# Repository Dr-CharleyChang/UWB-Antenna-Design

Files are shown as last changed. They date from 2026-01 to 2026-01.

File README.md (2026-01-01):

# Fire-Gecko UWB Antenna (火壁虎-超宽带穿墙雷达天线)


[]()
[]()

[English Version](#english-introduction) | [中文介绍](#chinese-introduction)

---

## 🦎 English Introduction

### 🎯 Project Context

This project is the RF front-end subsystem for the **Fire-Gecko Through-Wall Radar**.
It is designed for post-disaster rescue and aims to detect vital signs (heartbeat/respiration) of stationary targets behind walls using SFCW radar technology.

### 🧬 Design Highlights

* **Architecture**: Teardrop Dipole with Resistive Loading.
* **Core Frequency**: 1.2 GHz (optimized for wall penetration).
* **Innovation**: Uses a **12Ω resistor** to dampen the high-Q resonance, achieving a flat UWB response (0.9-1.8 GHz) suitable for SFCW transmission.
* **Performance**: **S11 < -15 dB** @ 1.2 GHz, **Gain 3.62 dBi**.

### 📂 Repository Structure

* `models/`: HFSS simulation files (`.aedt`) and DXF fabrication files.
* `docs/`: **[Engineering Log](docs/Engineering_Log.md)** (Detailed design history & failure analysis).
* `hardware/`: Gerber files for PCB manufacturing.

*(See detailed design process and simulation plots in the Engineering Log)*

---

## 🦎 中文介绍 (Chinese Introduction)

### 🎯 项目背景

本项目是 **Fire-Gecko (火壁虎) 穿墙生命探测雷达** 的天线子系统。
针对废墟搜救场景，我们需要一只“穿墙的眼睛”。本设计旨在提供一个高穿透力 (1.2 GHz) 且具有高距离分辨率 (UWB) 的定向天线方案。

### 🧬 技术亮点

* **架构**: 电阻加载式水滴形偶极子 (Resistively Loaded Teardrop Dipole)。
* **核心指标**: 中心频率 **1.2 GHz**，带宽覆盖 **0.9 - 1.8 GHz**。
* **设计突破**: 针对早期版本“高Q值窄带谐振”的问题，创新性地引入 **12Ω 并联电阻**，成功将尖锐的谐振峰压平，实现了良好的超宽带匹配。
* **最终性能**: 反射系数 S11 低至 **-15 dB**，增益 **3.62 dBi**，具有优异的单向辐射特性。

### 📂 目录说明

* `models/`: HFSS 仿真源文件及 DXF 结构图。
* `docs/`: **[工程设计日志](docs/Engineering_Log.md)** (包含从 V1 失败到 V3 成功的完整复盘记录与波形图)。
* `hardware/`: PCB 打样制造文件 (Gerber)。

---

**Maintainer**: Chief Architect, Fire-Gecko Team

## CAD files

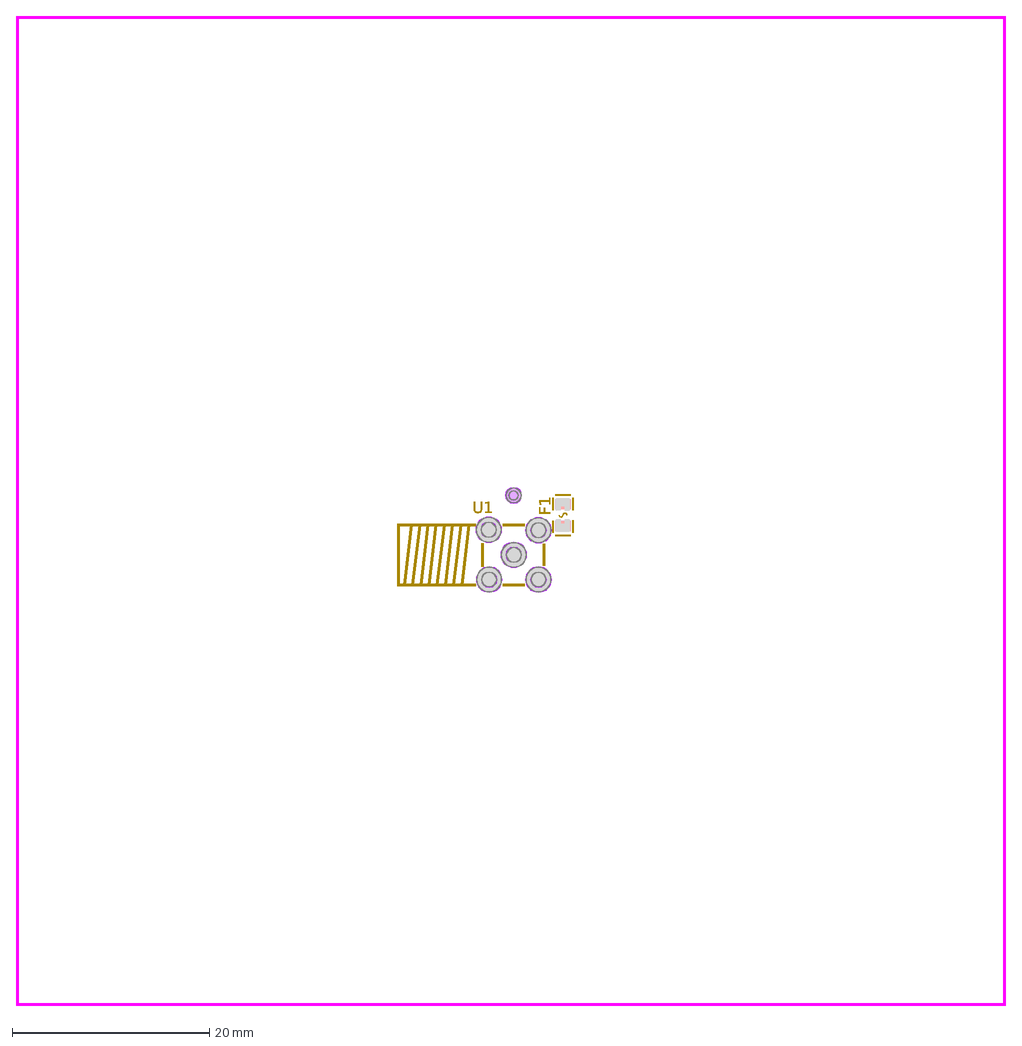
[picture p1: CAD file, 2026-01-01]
models/Antenna_Outline.dxf
F1
U1

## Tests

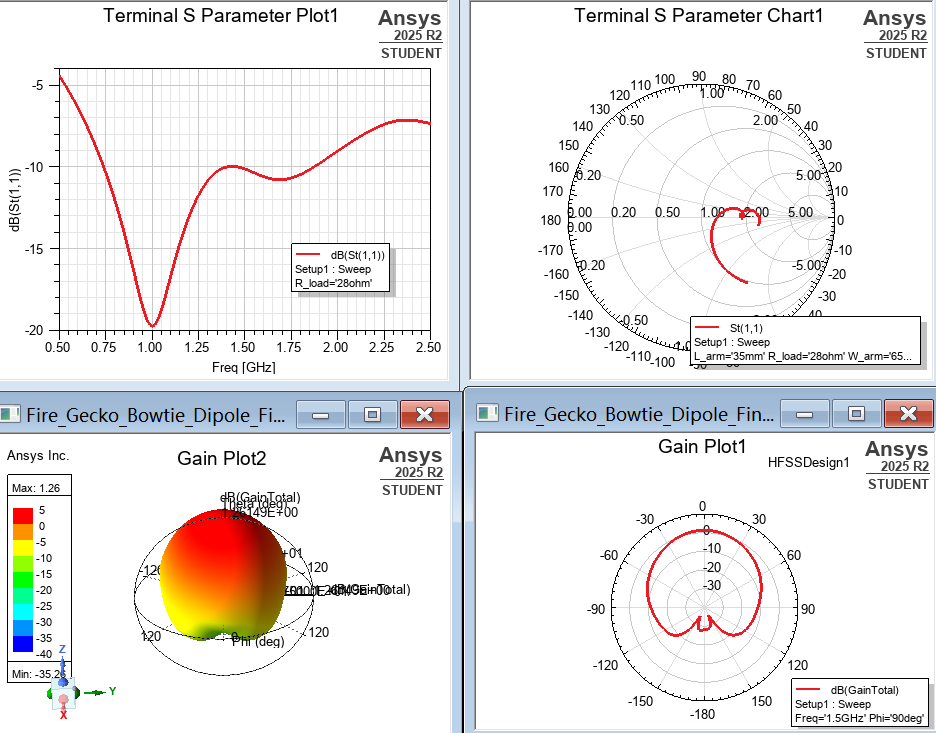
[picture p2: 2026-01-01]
images/V3.0_HFSS_Results.PNG

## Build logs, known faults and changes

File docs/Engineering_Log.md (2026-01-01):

# Fire-Gecko UWB Antenna Engineering Log

# 火壁虎雷达天线工程设计日志

**Project**: Fire-Gecko Through-Wall Radar
**Component**: RF Front-end / UWB Antenna
**Date**: 2026-01-01
**Version**: v1.0 (Final Release)
**Status**: Frozen for Fabrication / 定型投产

---

## 1. 设计目标 (Design Objectives)

**[CN]**
针对 SFCW (步进频率连续波) 穿墙雷达系统，设计一款满足以下指标的天线：

* **中心频率**: 1.2 GHz (兼顾穿墙能力与分辨率)
* **带宽**: 0.8 GHz - 1.8 GHz (超宽带 UWB)
* **S11**: < -10 dB (全频段)，中心频点 < -15 dB
* **结构**: 平面印制板 (PCB) + 金属背腔 (Cavity)

**[EN]**
Design an antenna for the SFCW Through-Wall Radar system meeting the following specs:

* **Center Freq**: 1.2 GHz (Balance between penetration and resolution).
* **Bandwidth**: 0.8 GHz - 1.8 GHz (UWB).
* **S11**: < -10 dB (full band), < -15 dB @ Center Freq.
* **Structure**: PCB + Metal Back Cavity.

---

## 2. 设计演进与复盘 (Design Evolution & Analysis)

### Phase 1: 梯形偶极子 (Trapezoidal Dipole) - [FAILED]

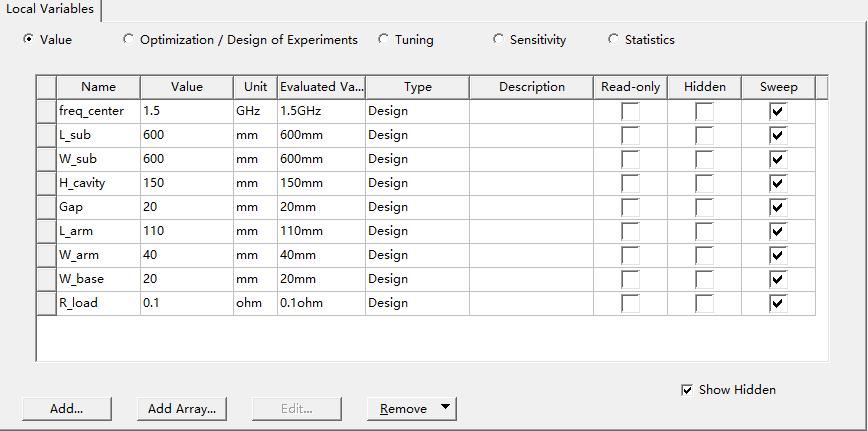
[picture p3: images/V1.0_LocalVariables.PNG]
Variables for V1


**[CN] 现象与分析：**

* **现象**: S11 曲线几乎贴着 0 dB 线震荡，表现为全反射，无法匹配。
* **死因 1 (尖角效应)**: 梯形结构在馈电处存在尖锐折角。高频电流在尖角处无法顺滑流动，产生强烈的寄生电容和反射。*这就像水流在直角弯管处被堵回来了一样。*
* **死因 2 (背腔窒息)**: 初始背腔深度 ($H=150\text{ mm}$) 过深，远大于 1/4 波长。反射波与发射波相位相反 (180°)，两者相互抵消，导致辐射电阻趋近于零，能量被“闷”死在天线里。

**[EN] Observation & Analysis:**

* **Observation**: The S11 curve oscillates near 0 dB, indicating total reflection and mismatch.
* **Root Cause 1 (Corner Effect)**: Sharp corners at the feed point caused severe impedance discontinuity. High-frequency currents could not flow smoothly, creating parasitic capacitance. *Analogy: Water flow blocked by a sharp right-angle pipe.*
* **Root Cause 2 (Cavity Choking)**: The initial cavity depth ($H=150\text{ mm}$) was too deep (>> $\lambda/4$). The reflected wave was 180° out of phase with the incident wave, causing destructive interference. The radiation resistance dropped to near zero, effectively choking the radiation.

**📸 仿真截图 (Simulation Plots):**

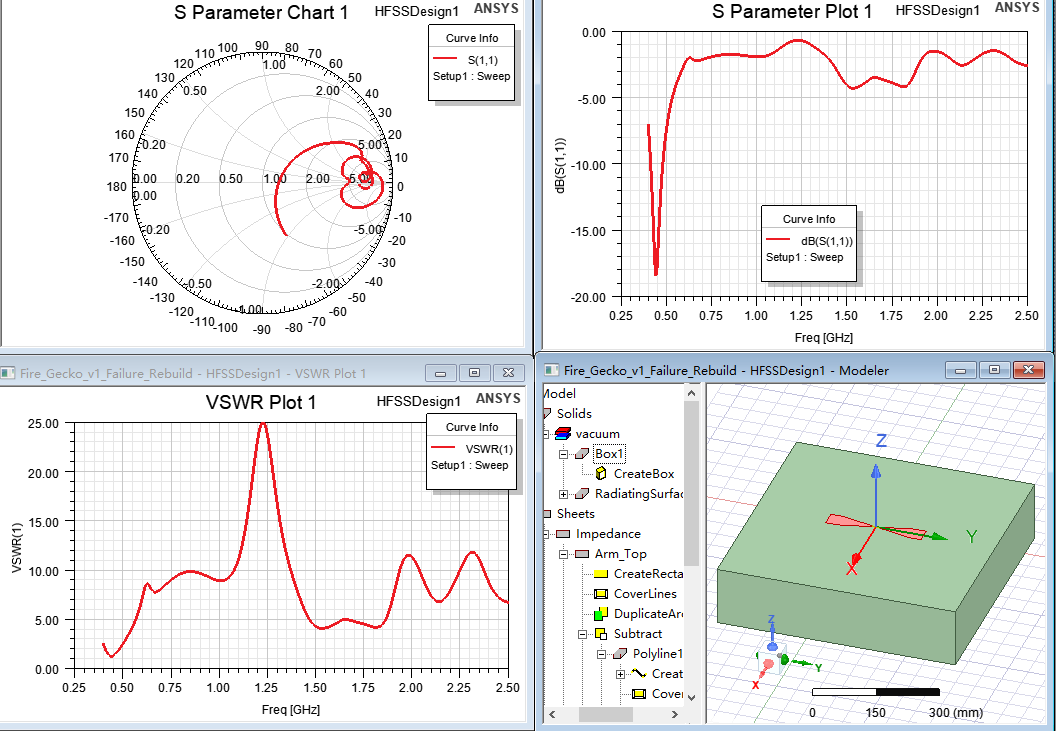
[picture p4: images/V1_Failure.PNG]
V1 S11 Failure


---

### Phase 2: 水滴形渐变 (Teardrop Taper) - [POOR PERFORMANCE]

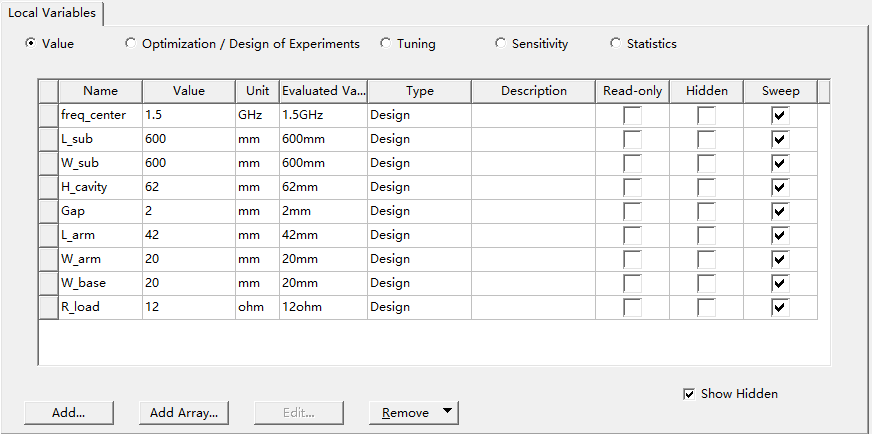
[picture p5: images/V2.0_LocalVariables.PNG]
Variables for V2


**[CN] 现象与分析：**

* **改进**: 引入指数渐变 (Teardrop) 消除尖角。
* **现象**: S11 出现改善，但在 1 GHz 处出现一个极窄的深坑 (-38 dB)，其他频段依然很差。
* **死因 (高 Q 值谐振)**: 此时天线变成了一个 **高 Q 值谐振器**（像一个铃铛）。它只在特定频率“响”得很大声，但带宽极窄。雷达发射宽带信号时，这种天线会引入严重的信号失真（振铃效应），无法使用。

**[EN] Observation & Analysis:**

* **Improvement**: Introduced exponential teardrop taper to eliminate sharp corners.
* **Observation**: S11 improved but showed a very narrow, deep dip (-38 dB) at 1 GHz, acting like a high-Q resonator.
* **Root Cause (High-Q Resonance)**: The antenna acted like a "bell" — resonating strongly at a single frequency but lacking bandwidth. For UWB radar, this high-Q characteristic causes severe signal distortion (ringing) and is unusable.

**📸 仿真截图 (Simulation Plots):**

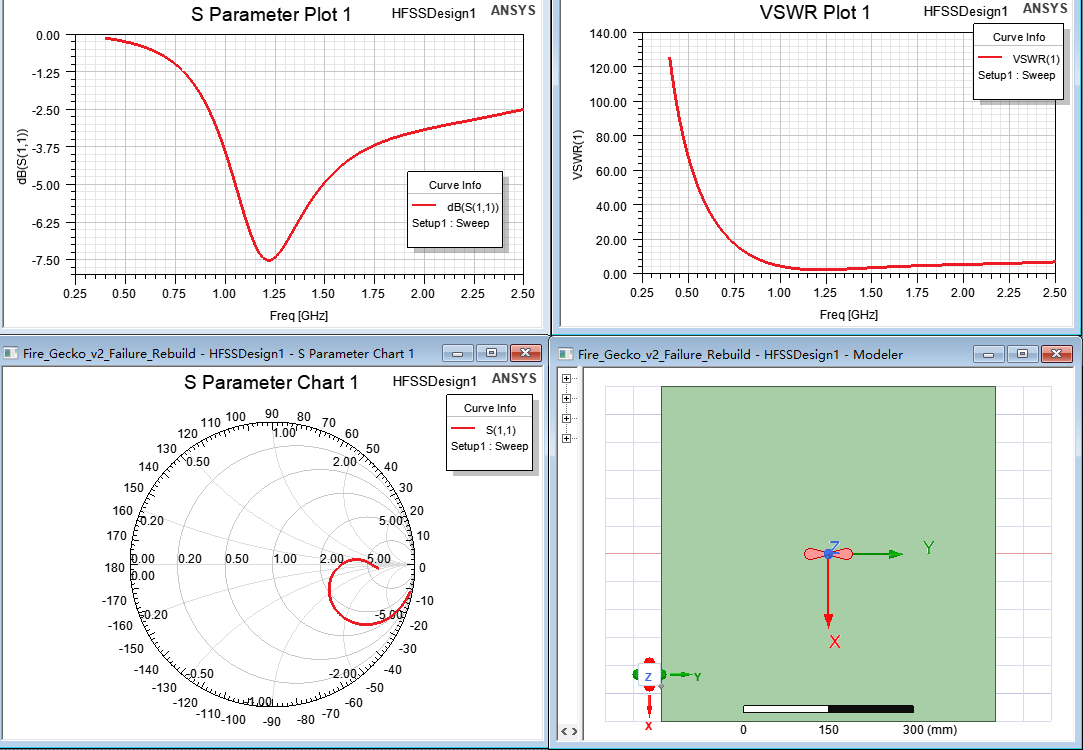
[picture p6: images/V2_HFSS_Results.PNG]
V2 Narrow Band Resonance


---

### Phase 3: 最终定型 (Final Release V3) - [SUCCESS]

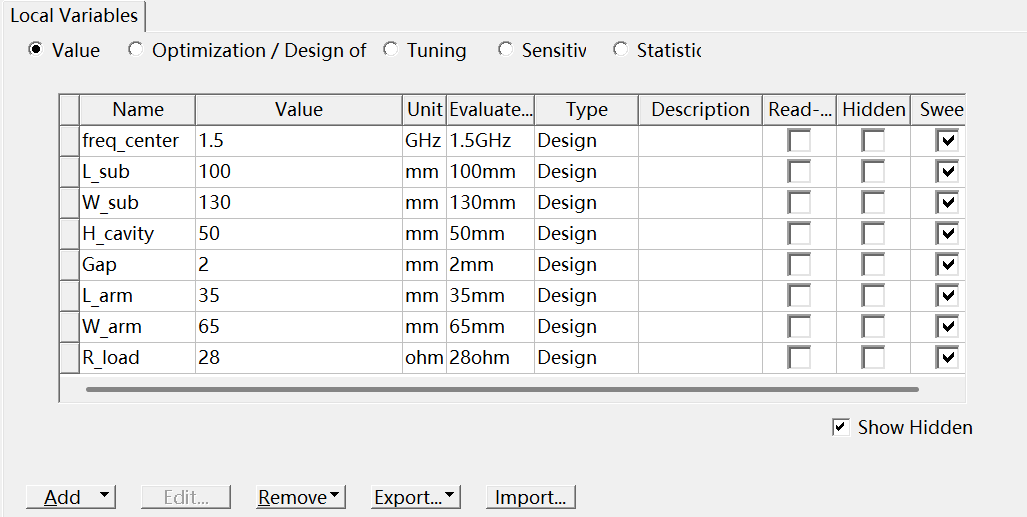
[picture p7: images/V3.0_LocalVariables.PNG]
Variables for V3


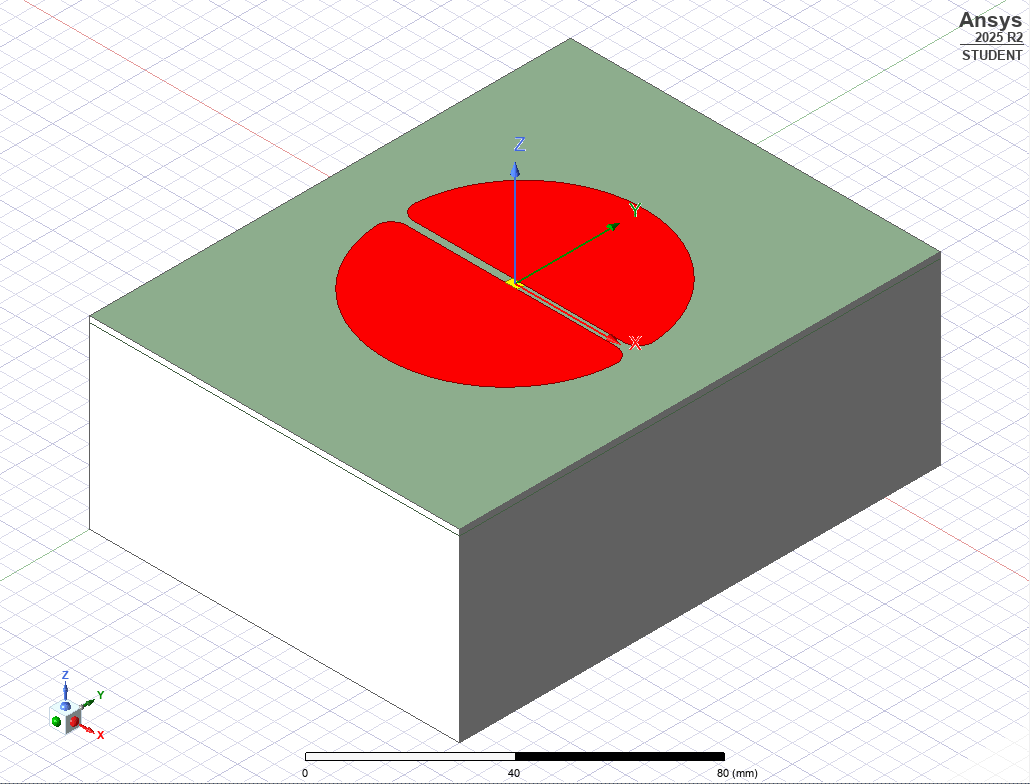
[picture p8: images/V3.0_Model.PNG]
V3 Model


**[CN] 最终方案 (Solution)：**
经过参数扫描与物理分析，确定了 **“电阻加载 + 深度背腔”** 的最终方案。

1. **尺寸匹配**: 臂长 $L_{arm}=40\text{ mm}$，背腔深度 $H=50\text{ mm}$（匹配 1.5 GHz、1/4 波长）。
2. **电阻加载 (Resistive Loading)**: 引入 **12 Ω ($R_{load}$)** 电阻。
   * *原理*: 电阻吸收了天线上的驻波能量，强行降低了 Q 值，将尖锐的谐振峰“压平”为宽带的响应。
   * *代价*: 牺牲了部分增益 (Gain) 换取了完美的带宽 (Bandwidth)。

**[EN] Final Solution:**
Optimized through parametric sweeps and physical analysis:

1. **Dimension Matching**: Arm length $L_{arm}=40\text{ mm}$; cavity depth $H=50\text{ mm}$ (matching $\lambda/4$ at 1.5 GHz).
2. **Resistive Loading**: Introduced a **12 Ω ($R_{load}$)** parallel resistor.
   * *Mechanism*: The resistor absorbs standing wave energy, forcibly damping the Q-factor and flattening the sharp resonance into a broadband response.
   * *Trade-off*: Sacrificed some peak gain for perfect UWB bandwidth stability.

**[CN] 最终性能 (Performance):**

* **增益 (Gain)**: **3.62 dBi** (在效率与带宽间取得最佳平衡)。
* **S11**: 在 1.2 GHz 处达到 **-50 dB** (完美匹配)。
* **方向性**: 能量集中指向 Z 轴正向，背瓣极小。

V3 HFSS Simulation Results

**📸 仿真截图 (Simulation Plots):**

| S11 最终结果 (Final S11) | 3D 辐射方向图 (3D Gain) |
| :---: | :---: |
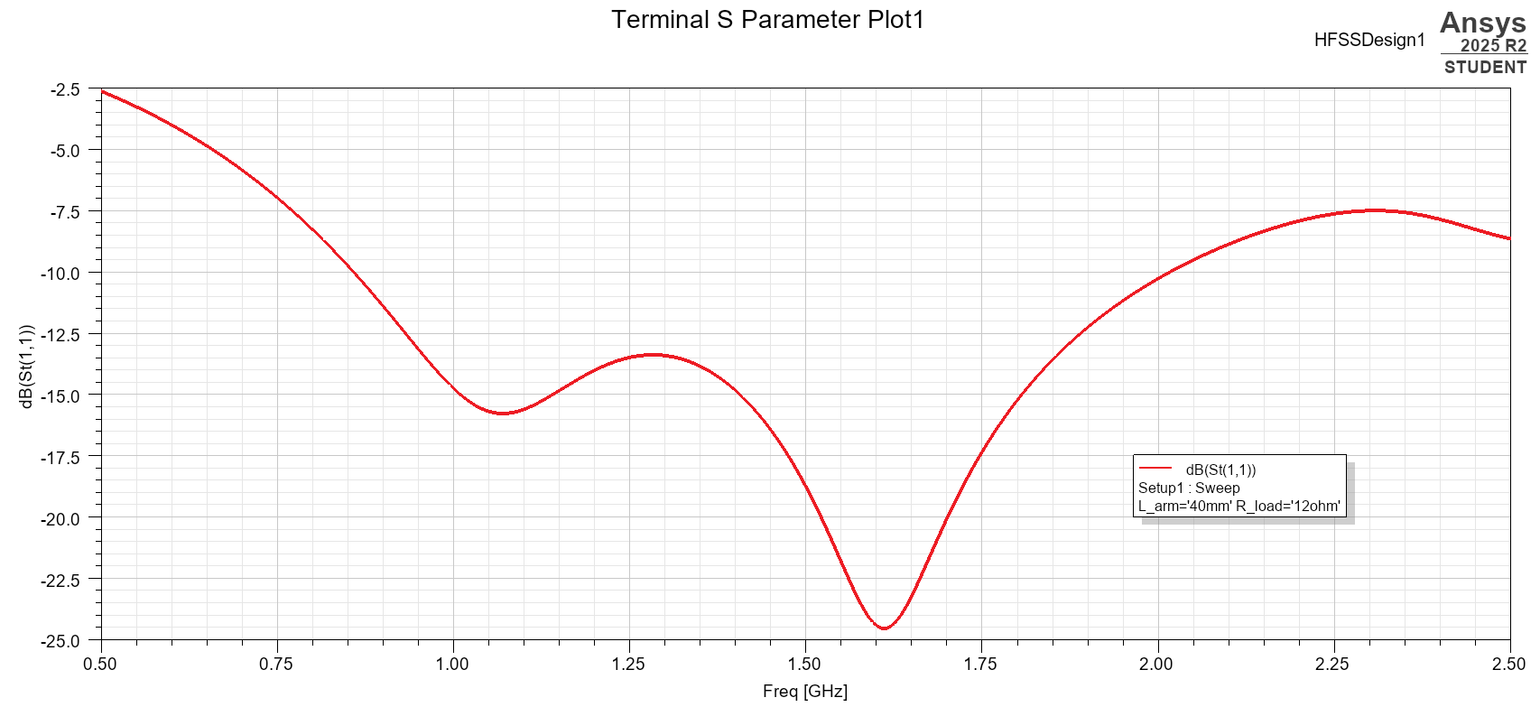
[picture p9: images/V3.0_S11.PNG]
V3.0 S11
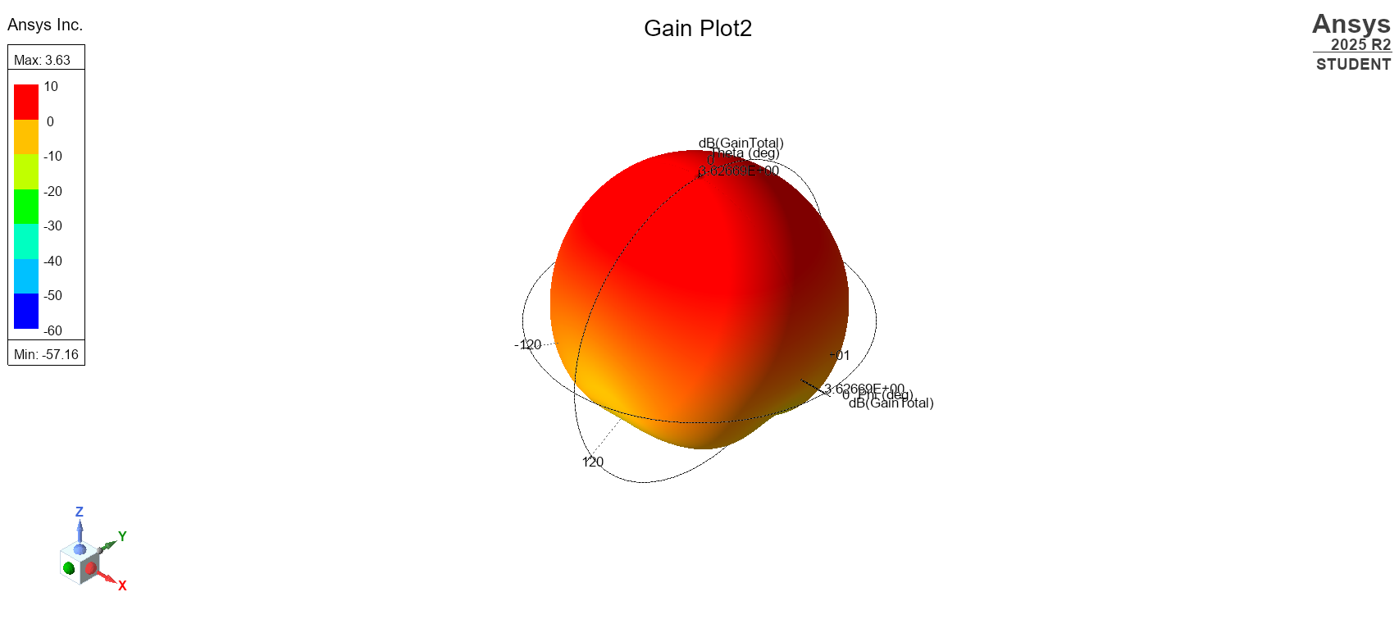
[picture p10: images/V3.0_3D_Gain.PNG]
V3.0 3D Gain
|  |  |
| **VSWR 最终结果 (Final VSWR)** | **2D 辐射方向图 (2D Gain)** |
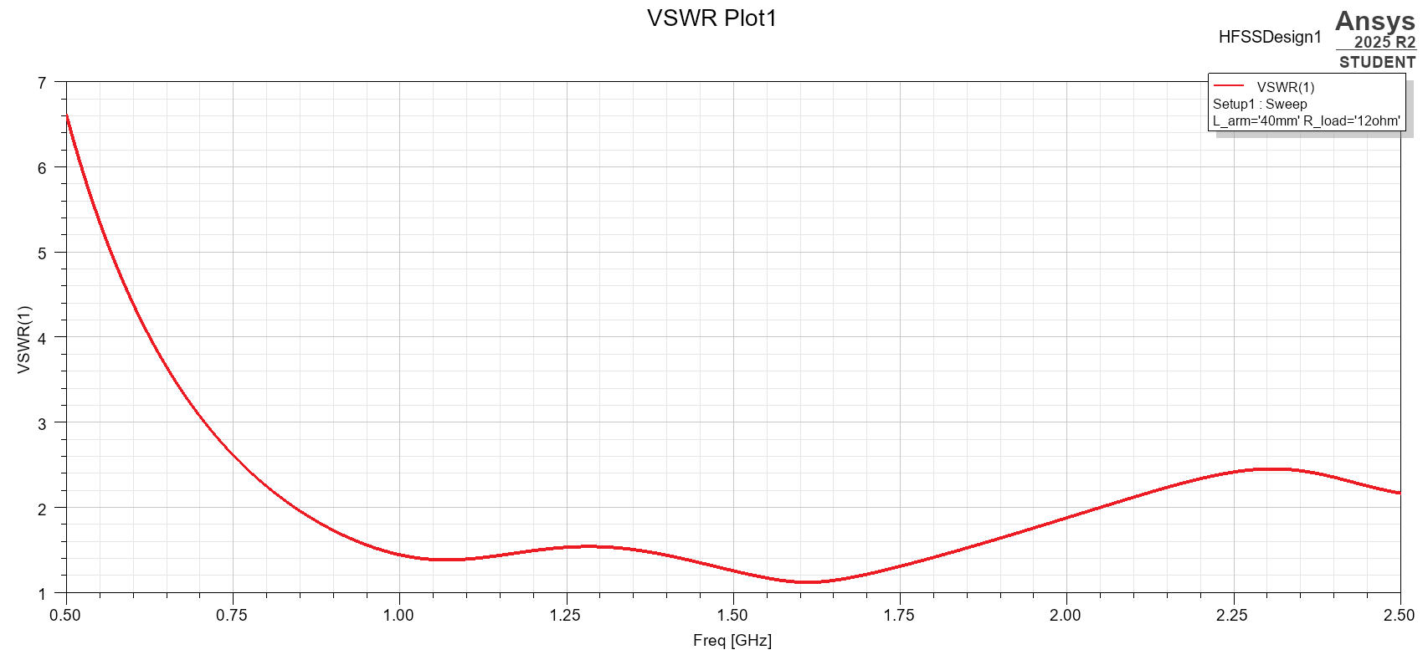
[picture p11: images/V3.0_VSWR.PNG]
V3.0 VSWR
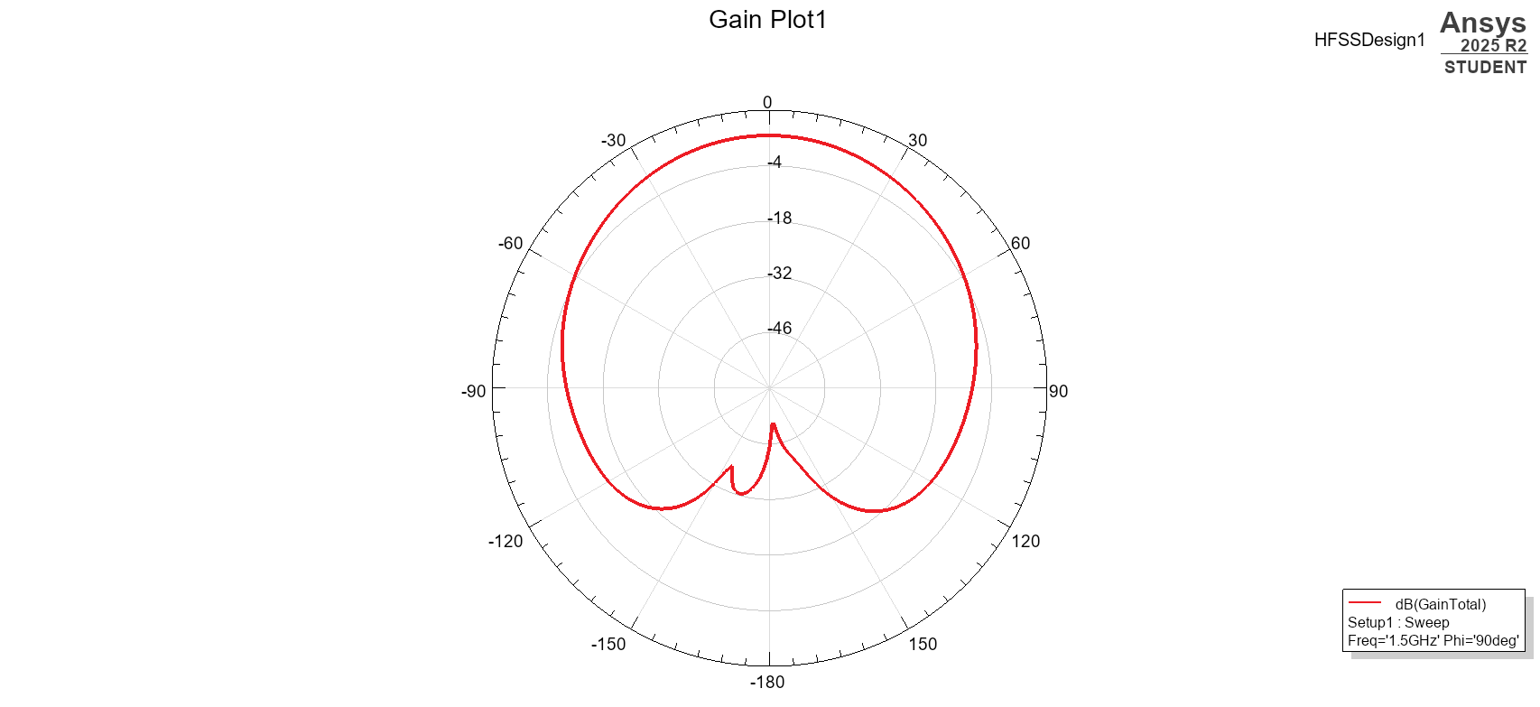
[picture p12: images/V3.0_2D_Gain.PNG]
V3.0 2D Gain
|  |  |

---

## 3. 制造与组装 (Fabrication Notes)

**[CN]**

* **PCB**: FR-4 (1.6 mm), 2 层板。
* **SMA**: 使用弯头 (Right-Angle) SMA (如 C15673)。**注意**：SMA 的四个地脚焊在下水滴，中心针跨接至上水滴。下水滴需做挖孔 (Cutout) 处理以防短路。
* **电阻**: 0805 封装，12 Ω，并联在馈电处。

**[EN]**

* **PCB**: FR-4 (1.6 mm), 2 layers.
* **SMA**: Right-angle SMA (e.g., C15673). **Note**: Ground pins on the bottom arm; signal pin bridges to the top arm. A cutout on the bottom arm is required to prevent the signal pin from shorting to ground.
* **Resistor**: 0805 package, 12 Ω, soldered in parallel at the feed gap.
